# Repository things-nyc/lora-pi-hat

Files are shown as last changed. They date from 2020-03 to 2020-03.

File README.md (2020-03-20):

# lora-pi-hat
Raspberry Pi HAT for mPCIe LoRa gateway cards

Untested
* jumpers are probably unnecessary because SPI pins are independent
* u-blox module can be swapped for *much* cheaper alternative
* gateway current consumption @3.3V ~ 500mA, DC/DC designed for 1A

| Pin | mini PCIe  | MTAC | RAK |
|-----|---|---|---|
| 1 | WAKE# | | |
| 2 | 3.3Vaux | VDD_3V3 | VDD_3V3  |
| 3 | COEX1 | | |
| 4 | GND | GND | GND |
| 5 | COEX2 | SPI_MOSI | |
| 6 | 1.5Vaux | | |
| 7 | CLKREQ# | SPI_MISO | |
| 8 | UIM_PWR | | |
| 9 | GND | GND | GND |
| 10  | UIM_DATA | | |
| 11  | REFCLK- | | |
| 12  | UIM_CLK | SPI_NCS | |
| 13  | REFCLK+ | SPI_CLK | |
| 14  | UIM_RESET  | ? | |
| 15  | GND | GND | GND |
| 16  | UIM_VPP | | |
| 17  | Reserved | | |
| 18  | GND | GND | GND |
| 19  | Reserved | | GPS_PPS  |
| 20  | W_DISABLE# | | |
| 21  | GND | GND | GND |
| 22  | PERST# | RESET | RESET |
| 23  | PERn0 | VDD_5V | |
| 24  | 3.3Vaux | VDD_3V3 | VDD_3V3  |
| 25  | PERp0 | VDD_5V | |
| 26  | GND | GND | GND |
| 27  | GND | EEPROM_A1 | GND |
| 28  | 1.5Vaux | GPS_PPS | |
| 29  | GND | EEPROM_A2 | GND |
| 30  | SMB_CLK | I2C_SCL | |
| 31  | PETn0 | | |
| 32  | SMB_DATA | I2C_SDA | |
| 33  | PETp0 | | |
| 34  | GND | GND | GND |
| 35  | GND | GND | GND |
| 36  | USB_D- | | |
| 37  | GND | GND | GND |
| 38  | USB_D+ | | |
| 39  | 3.3Vaux | VDD_3V3 | VDD_3V3  |
| 40  | GND | GND | GND |
| 41  | 3.3Vaux | VDD_3V3 | VDD_3V3  |
| 42  | LED_WWAN#  | ? | |
| 43  | GND | GND | GND |
| 44  | LED_WLAN#  | | |
| 45  | Reserved | | SPI_CLK  |
| 46  | LED_WPAN#  | | |
| 47  | Reserved | | SPI_MISO |
| 48  | 1.5Vaux | | |
| 49  | Reserved | | SPI_MOSI |
| 50  | GND | GND | GND |
| 51  | Reserved | | SPI_NCS  |
| 52  | 3.3Vaux | VDD_3V3 | VDD_3V3  |

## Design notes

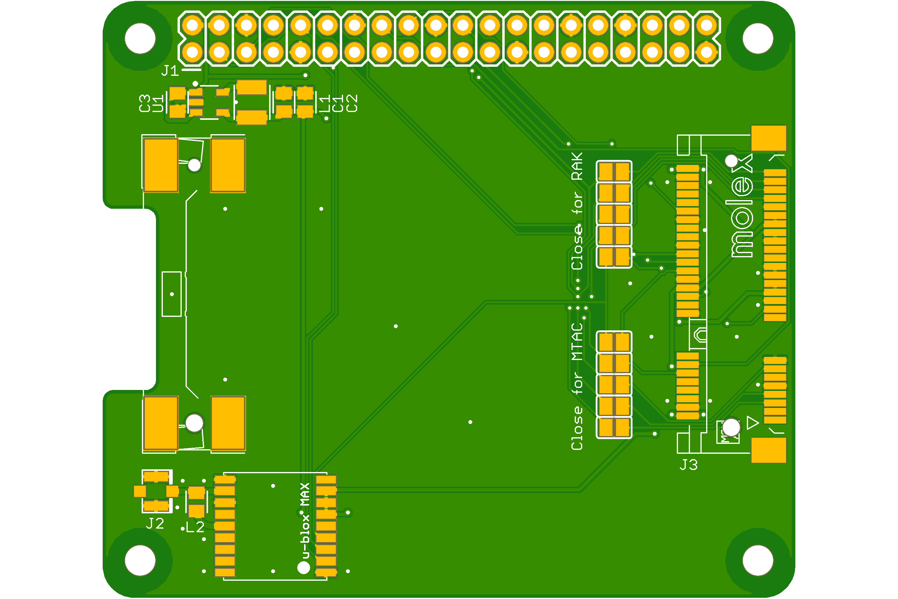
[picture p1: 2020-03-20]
lora-pi-hat-brd.png

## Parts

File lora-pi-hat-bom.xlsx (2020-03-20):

Qty | Parts | Value | Device | Package | Digikey PN | Description | Notes
3 | C1, C2, C3 | 10u | C-US-0805 | CAPC2012X125N | 587-1300-1-ND | Capacitor
1 | L1 | 2.2u | L-US-1210 | INDC3225X250N | 587-2427-1-ND | Buck Inductor
1 | L2 | 47n | L-US-0805 | INDC2012X125N | 2035-1277-1-ND | Bias Inductor
1 | J3 | 679105700 | 679105700 | 679105700 | WM3471CT-ND | MOLEX MINI PCI EXPRESS CONNECTOR
1 |  |  |  |  | WM3294CT-ND | MOLEX MINI PCI EXPRESS LATCH
1 | U2 | MAX-M8 | MAX-M8 | MAX-M8 | 672-MAX-M8W-0-10CT-ND | u-blox MAX GNSS module | Save $ with ATGM336H from LCSC
1 | J1 | RASPBERRYPI-40-PIN-GPIO | RASPBERRYPI-40-PIN-GPIO | 2X20 | S6104-ND | Raspberry Pi GPIO Header
1 | U1 | SC189ZSKTRT | SC189ZSKTRT | SOT95P280X120-5N | SC189ZSKCT-ND | Buck Regulator
1 | J2 | U.FL | U.FL2PIN | U.FL | A118077CT-ND | SMD Antenna Connector - U.FL

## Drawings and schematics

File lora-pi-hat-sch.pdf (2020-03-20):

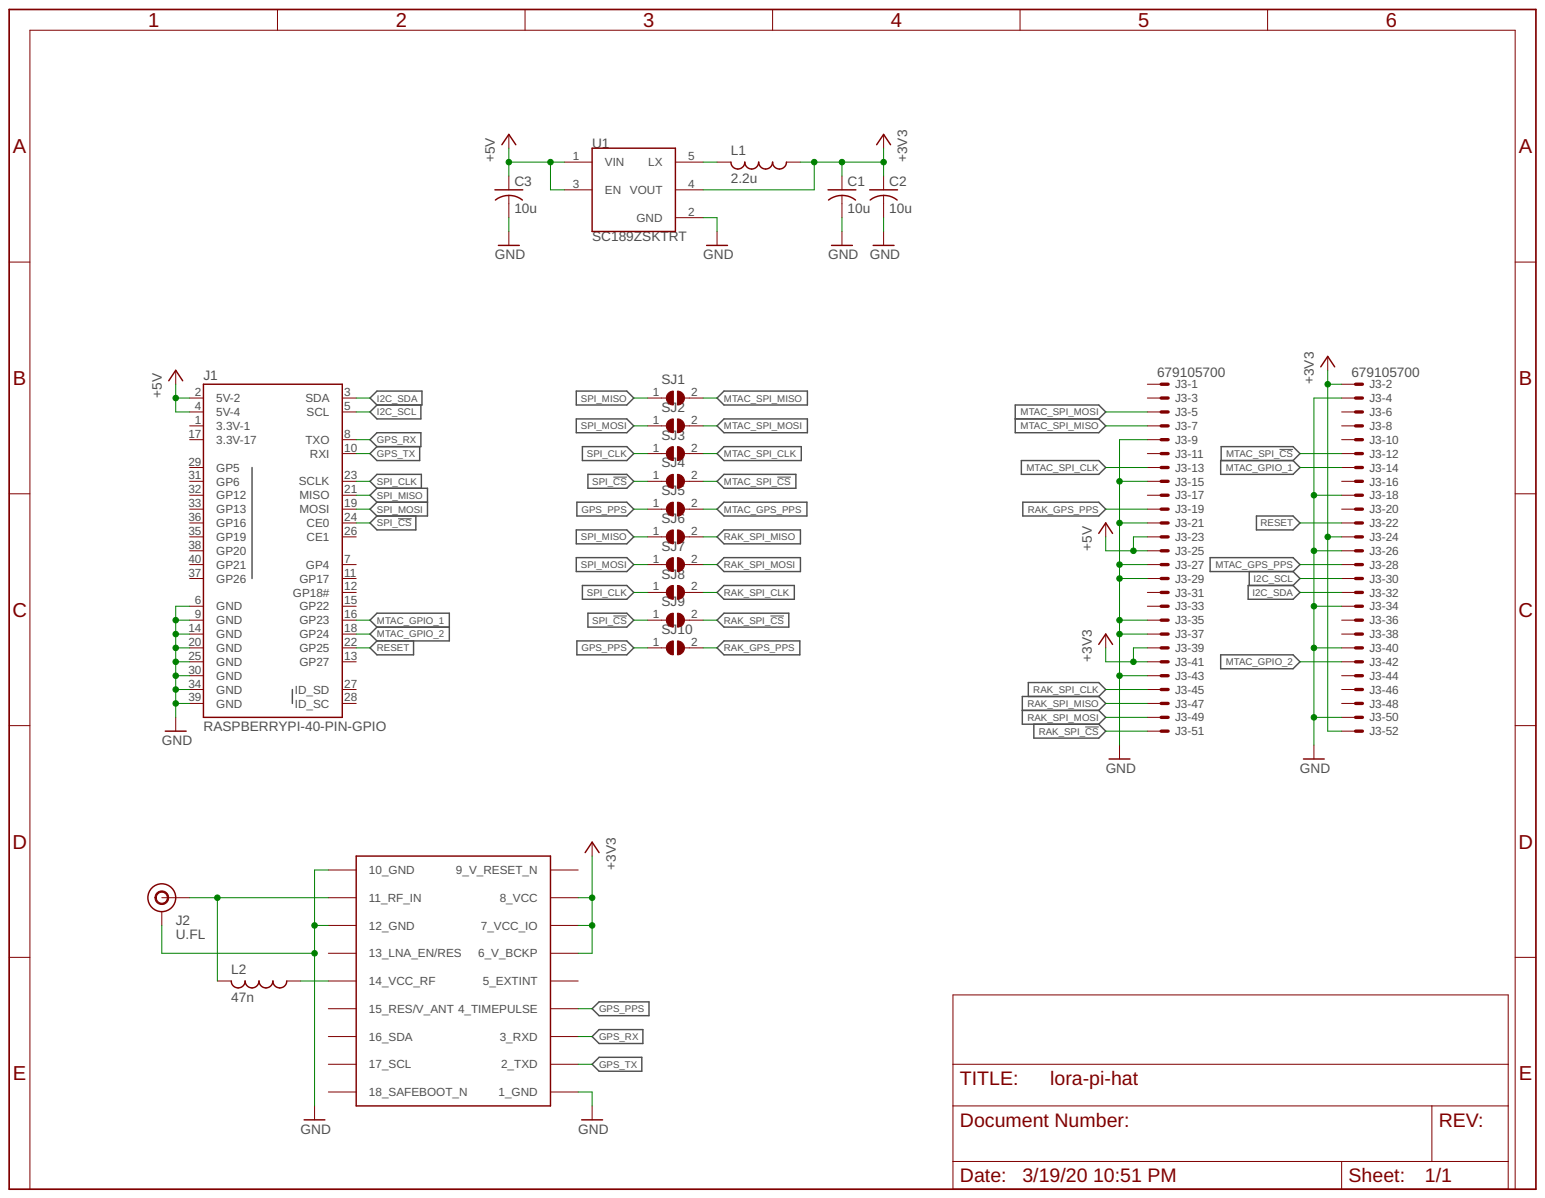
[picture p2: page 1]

Document Number: | REV:

Date: 3/19/20 10:51 PM | Sheet: 1/1

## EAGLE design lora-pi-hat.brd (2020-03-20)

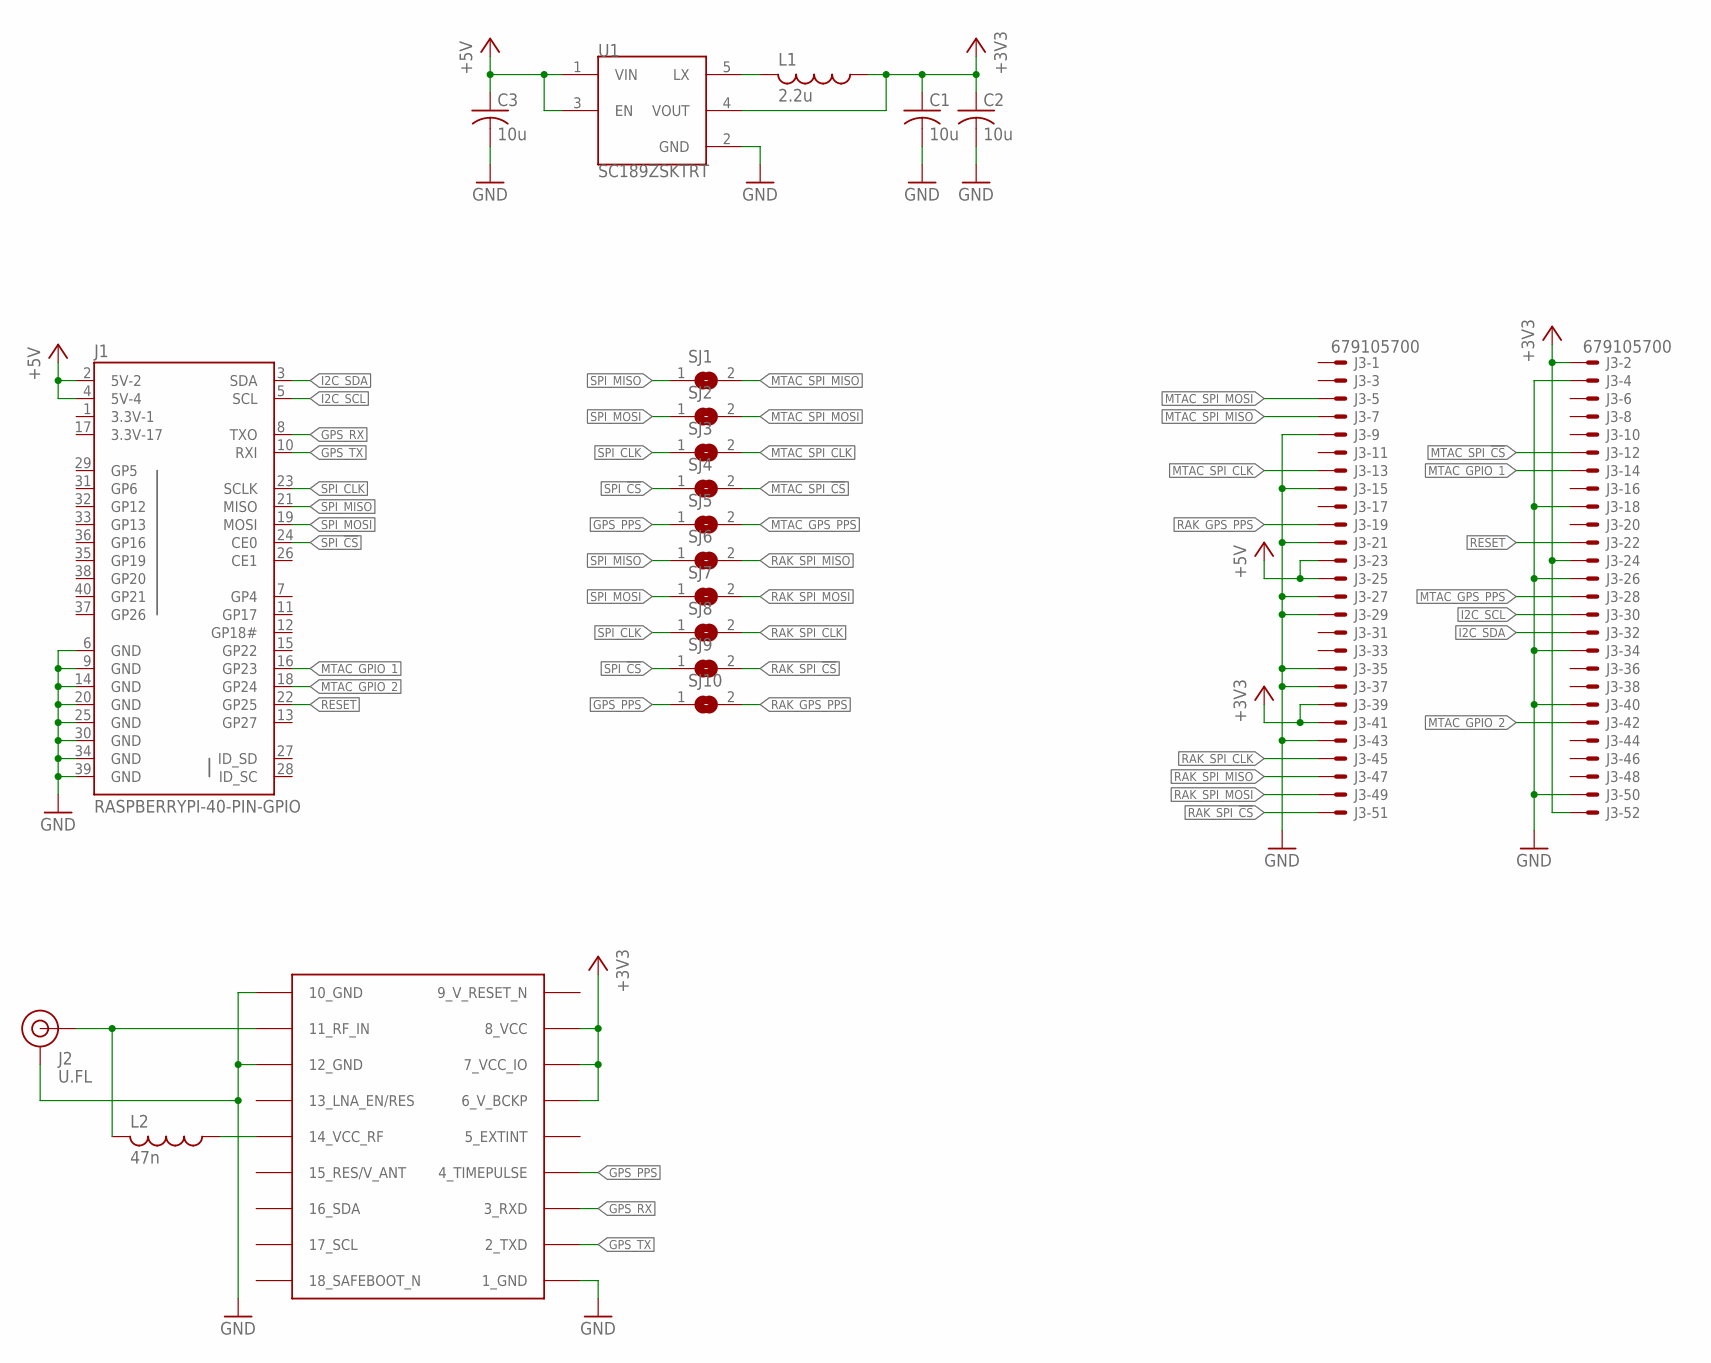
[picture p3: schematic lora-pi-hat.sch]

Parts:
C1, C2, C3: 10u; CAPC2012X125N
J1: RASPBERRYPI-40-PIN-GPIO; 2X20
J2: U.FL
J3: 679105700
L1: 2.2u; INDC3225X250N
L2: 47n; INDC2012X125N
SJ1, SJ2, SJ3, SJ4, SJ5, SJ6, SJ7, SJ8, SJ9, SJ10: SJ
U1: SC189ZSKTRT; SOT95P280X120-5N
U2: MAX-M8

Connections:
3.3V-1: J1.1 (3.3V-1)
3.3V-17: J1.17 (3.3V-17)
9_V_RESET_N: U2.9_RESET_N (9_V_RESET_N)
+3V3: C1.1, C2.1, J3.2, J3.24, J3.39, J3.41, J3.52, L1.1, U1.4 (VOUT), U2.6_V_BCKP, U2.7_VCC_IO, U2.8_VCC
+5V: C3.1, J1.2 (5V-2), J1.4 (5V-4), J3.23, J3.25, U1.1 (VIN), U1.3 (EN)
GND: C1.2, C2.2, C3.2, J1.6 (GND), J1.9 (GND), J1.14 (GND), J1.20 (GND), J1.25 (GND), J1.30 (GND), J1.34 (GND), J1.39 (GND), J2.1 (GND), J2.2 (GND), J3.4, J3.9, J3.15, J3.18, J3.21, J3.26, J3.27, J3.29, J3.34, J3.35, J3.37, J3.40, J3.43, J3.50, U1.2 (GND), U2.1_GND, U2.10_GND, U2.12_GND
GPS_PPS: SJ5.1, SJ10.1, U2.4_TIMEPULSE
GPS_RX: J1.8 (TXO), U2.3_RXD
GPS_TX: J1.10 (RXI), U2.2_TXD
I2C_SCL: J1.5 (SCL), J3.30
I2C_SDA: J1.3 (SDA), J3.32
MTAC_GPIO_1: J1.16 (GP23), J3.14
MTAC_GPIO_2: J1.18 (GP24), J3.42
MTAC_GPS_PPS: J3.28, SJ5.2
MTAC_SPI_!CS: J3.12, SJ4.2
MTAC_SPI_CLK: J3.13, SJ3.2
MTAC_SPI_MISO: J3.7, SJ1.2
MTAC_SPI_MOSI: J3.5, SJ2.2
unnamed: L1.2, U1.5 (LX)
unnamed: L2.1, U2.14_VCC_RF
unnamed: J2.FEED (SIGNAL), L2.2, U2.11_RF_IN
RAK_GPS_PPS: J3.19, SJ10.2
RAK_SPI_!CS: J3.51, SJ9.2
RAK_SPI_CLK: J3.45, SJ8.2
RAK_SPI_MISO: J3.47, SJ6.2
RAK_SPI_MOSI: J3.49, SJ7.2
RESET: J1.22 (GP25), J3.22
SPI_!CS: J1.24 (CE0), SJ4.1, SJ9.1
SPI_CLK: J1.23 (SCLK), SJ3.1, SJ8.1
SPI_MISO: J1.21 (MISO), SJ1.1, SJ6.1
SPI_MOSI: J1.19 (MOSI), SJ2.1, SJ7.1

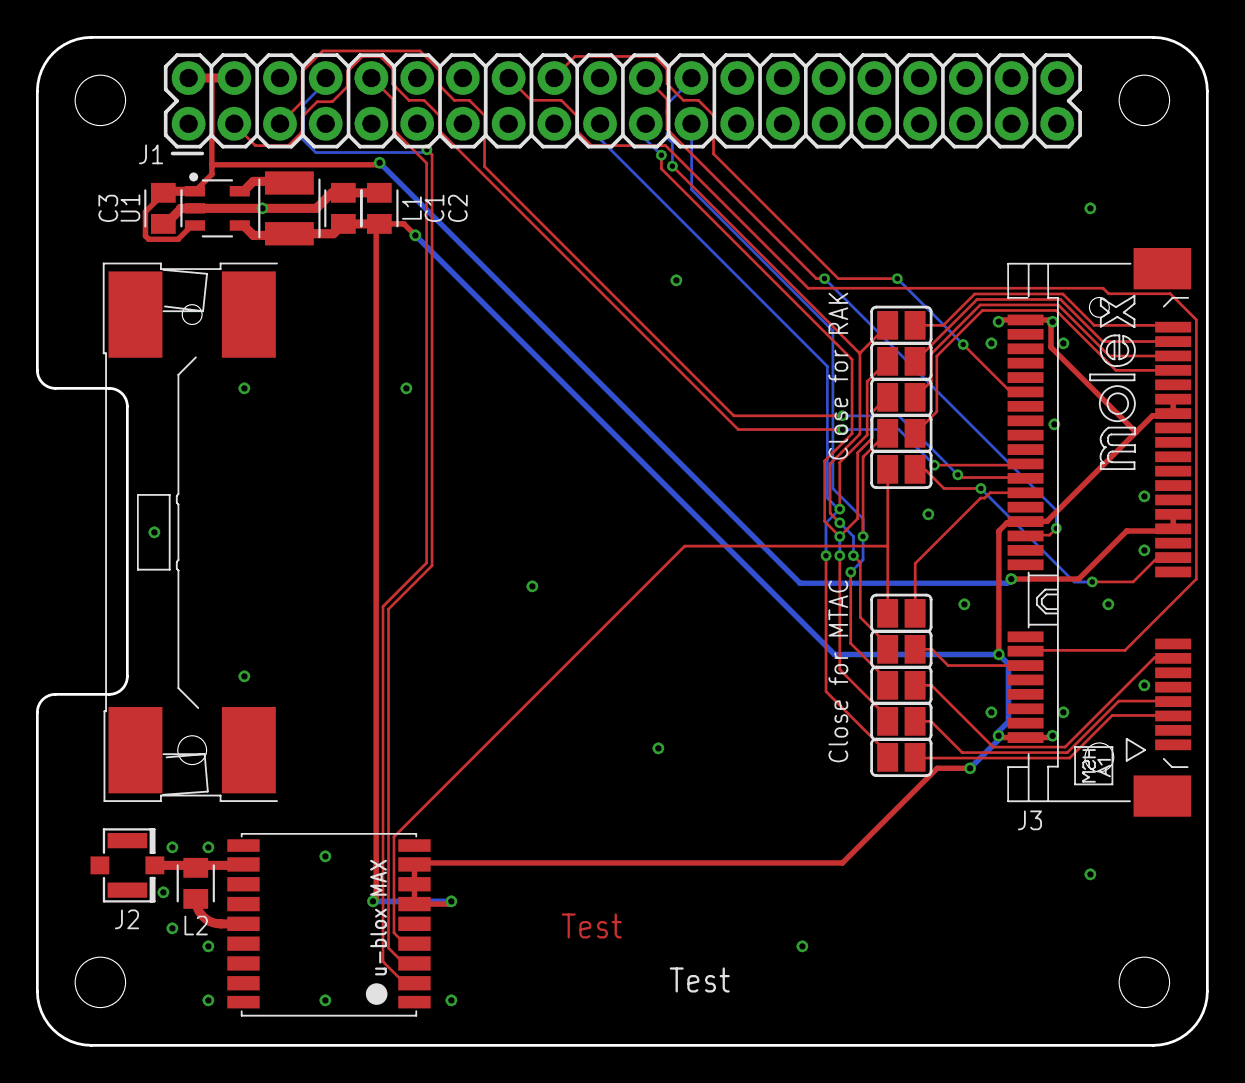
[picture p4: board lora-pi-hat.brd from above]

Board: 2 copper layers, 65.0 x 56.0 mm, 20 parts (0 on the bottom side), 28 nets.

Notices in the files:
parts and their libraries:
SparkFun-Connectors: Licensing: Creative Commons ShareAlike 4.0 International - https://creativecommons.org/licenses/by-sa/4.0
